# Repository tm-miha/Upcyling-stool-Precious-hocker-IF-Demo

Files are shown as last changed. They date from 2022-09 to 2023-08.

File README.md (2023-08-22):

<!--
SPDX-FileCopyrightText: regenholz <mail@regenholz.de>

SPDX-License-Identifier: CC-BY-NC-SA-4.0
-->

# Upcycling stool and side table furniture "Precious Hocker"

## General info and a bit of context

The "Precious Hocker" project was developed during the [Building workshops](https://www.interfacerproject.eu/news/buildworkshops/) of the [Interfacer Project](https://www.interfacerproject.eu/) by [regenholz](https://regenholz.de) and was cloned for demo purposes from the [gitlab.fabcity.hamburg](https://gitlab.fabcity.hamburg/hardware/interfacer-osh-build-workshops/upcycling-moebelbau-holz-preciousplastic ) account.

## Hardware Description

The "Precious Hocker" is an upcycling product used as a sitting stool or as a piece of furniture for storage in the living room (laptop, tablet, magazines, drinks, snacks, plants, etc.). The wood comes from discarded spruce planks from scaffolding construction, the plastic frame is cast from plastic waste (shredded plastic lids).

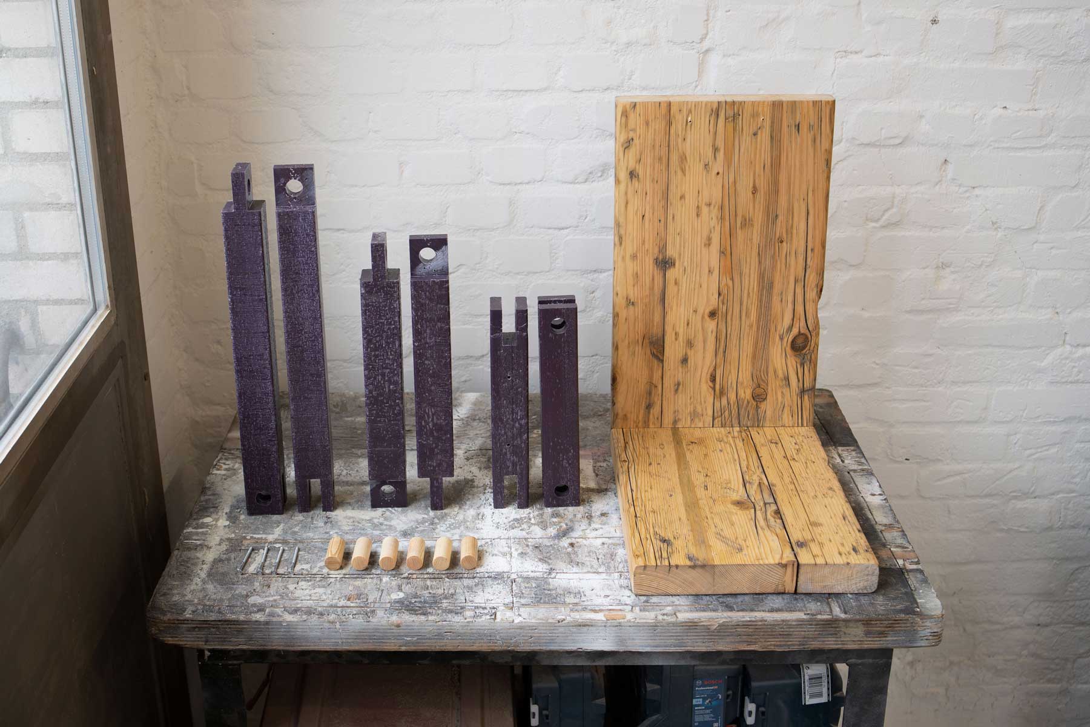
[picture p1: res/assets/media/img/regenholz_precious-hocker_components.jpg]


**Object:**

- Dimensions approx. 550x350x450 mm
- Weight approx. 5 kg

## Key Ressources

- [BOM file](bom.csv)
- [Dimensions](src/mech/dimension-drawing.md)
- [Workshop Description](doc/workshops/build/workshop-description+agenda_de.md)
- [Step-by-Step-Guide](doc/workshops/build/step-by-step_build-guideline.md)

## License

Hardware design, CAD and PCB files, BOM, settings and other technical or design files are released under the following license:
- CERN Open Hardware Licence Version 2 Weakly Reciprocal - **[CERN-OHL-W](/LICENSES/LICENSE_CERN_OHL_W_V2.txt)**

Assembly manual, pictures, videos, presentations, description text and other type of media are released under the following license:
- Creative-Commons-Attribution-NonCommercial-ShareAlike 4.0 International - **[CC-BY-NC-SA 4.0](/LICENSES/CC-BY-NC-SA-4.0.txt)**

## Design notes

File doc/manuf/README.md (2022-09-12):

# README `doc/manuf/`

Manufacturing instructions manual sources - Manufacturing means: Details about how to get from the sources under src/elec/ and src/mech/ to the actual parts, so this contains the meta-data about, and describes the process of 3D-printing, milling, carving, ... the individual parts. See also: doc/assembly/.

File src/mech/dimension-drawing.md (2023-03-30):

# Vermaßung

Die Dimensionen des Hockers lassen sich je nach Material und Stärke variieren.



## Vermaßung Objekt

- Tiefe: 450 mm
- Breite: 350 mm
- Höhe: 550 mm



## Zuschnitte Holzbohlen 

- Materialstärke: 45 mm
- Bohlenbreite: 350 mm
- 1x Platte 1, Länge: 450 mm Außenmaß auf 45°
- 1x Platte 2, Länge: 550 mm Außenmaß auf 45°

## Zuschnitte Plasktikbalken 

- Materialstärke: 52x52 mm
- 2x Balken 1, Länge: 350 mm
- 2x Balken 2, Länge: 405 mm
- 2x Balken 3, Länge: 505 mm

- 6x Löcher für Rundstäbe: Forstnerbohrer 22 mm Durchmesser

## Zuschnitte Rundstäbe

Durchmesser:22 mm
6x Rundstab, Länge: 52 mm

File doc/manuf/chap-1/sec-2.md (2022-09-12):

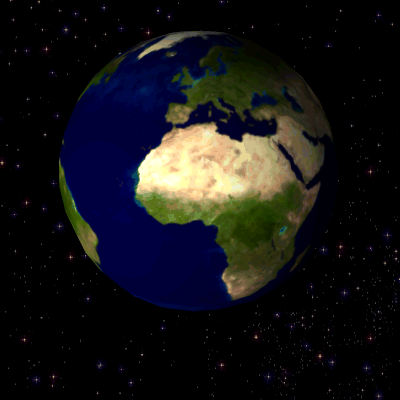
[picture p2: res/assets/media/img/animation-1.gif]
image X


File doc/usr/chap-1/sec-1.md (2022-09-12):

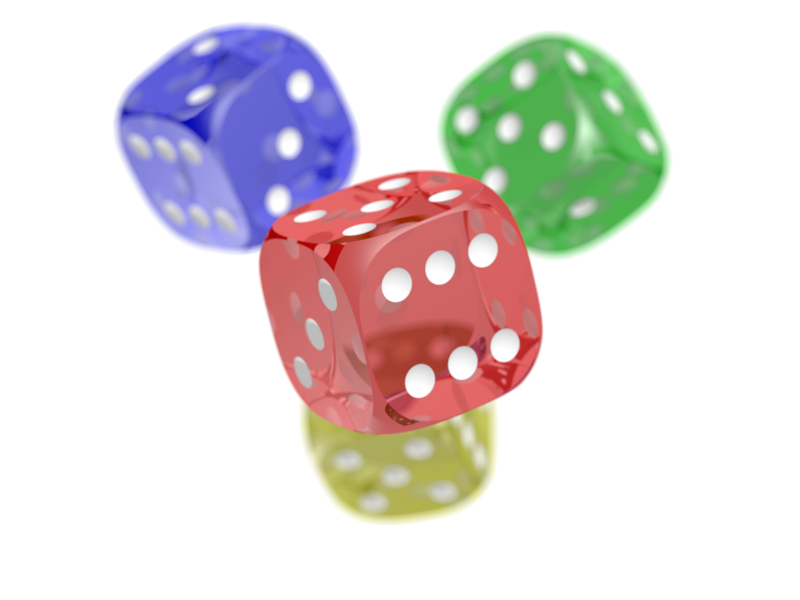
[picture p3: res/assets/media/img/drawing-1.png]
image X


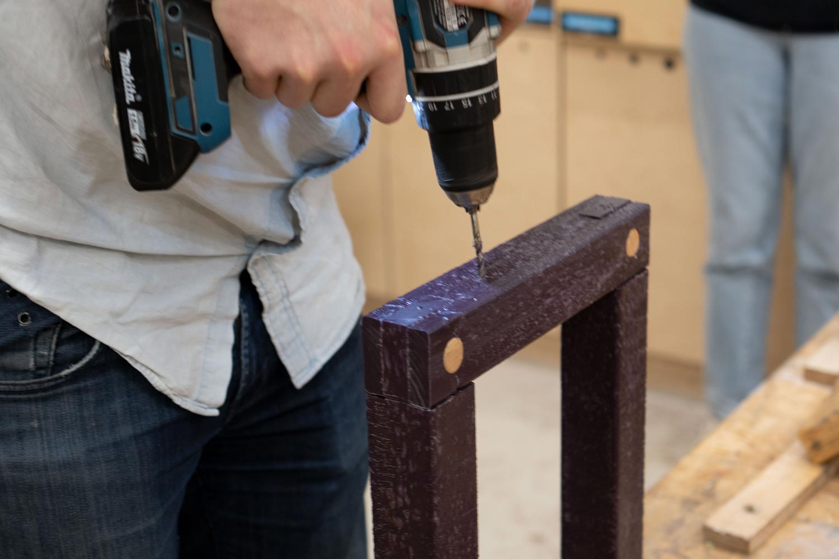
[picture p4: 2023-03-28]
res/assets/media/img/regenholz_precious-hocker_17-schraubloecher-vorbohren.jpg

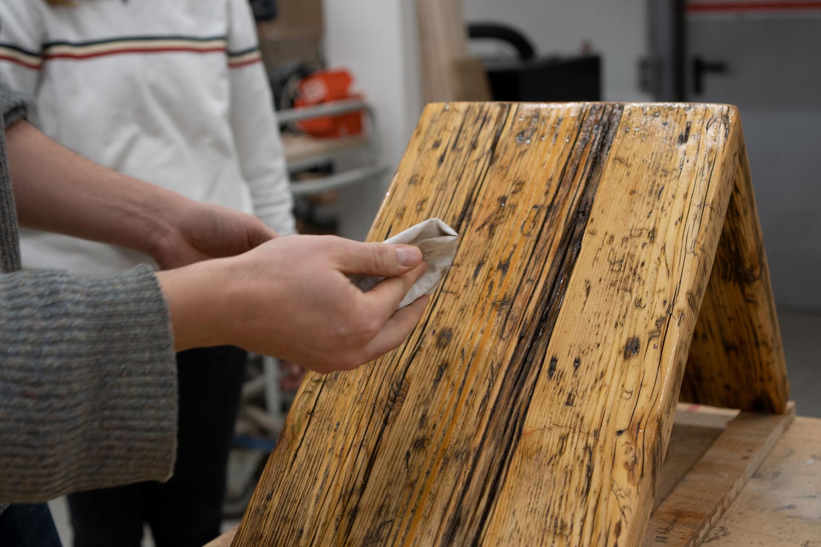
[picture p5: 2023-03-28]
res/assets/media/img/regenholz_precious-hocker_11-oelen.jpg

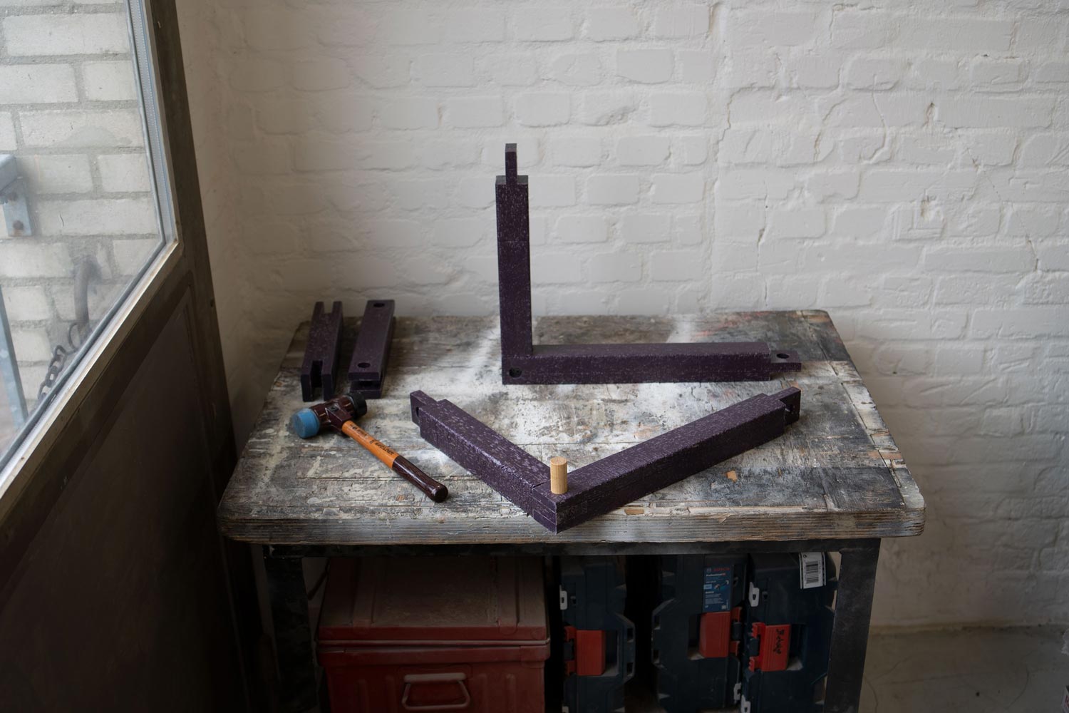
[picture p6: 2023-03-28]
res/assets/media/img/regenholz_precious-hocker_20-gestell-bauen.jpg

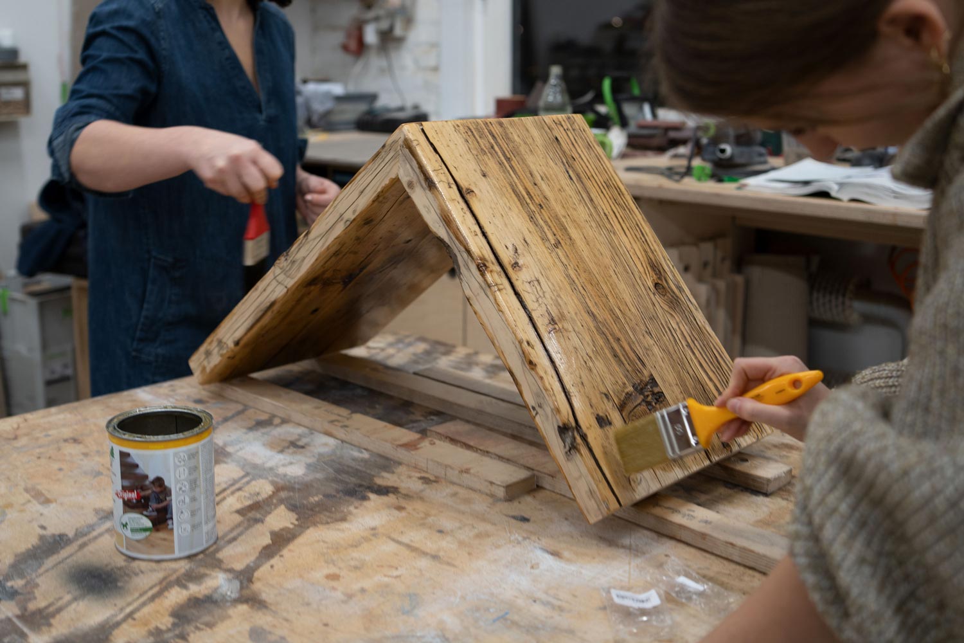
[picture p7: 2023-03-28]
res/assets/media/img/regenholz_precious-hocker_10-oelen.jpg

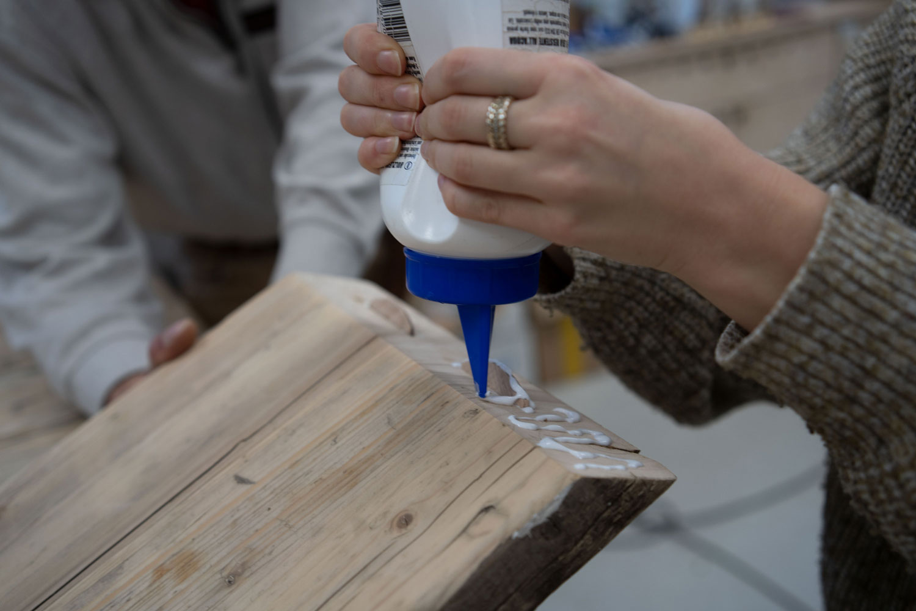
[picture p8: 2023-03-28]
res/assets/media/img/regenholz_precious-hocker_05-verleimen.jpg

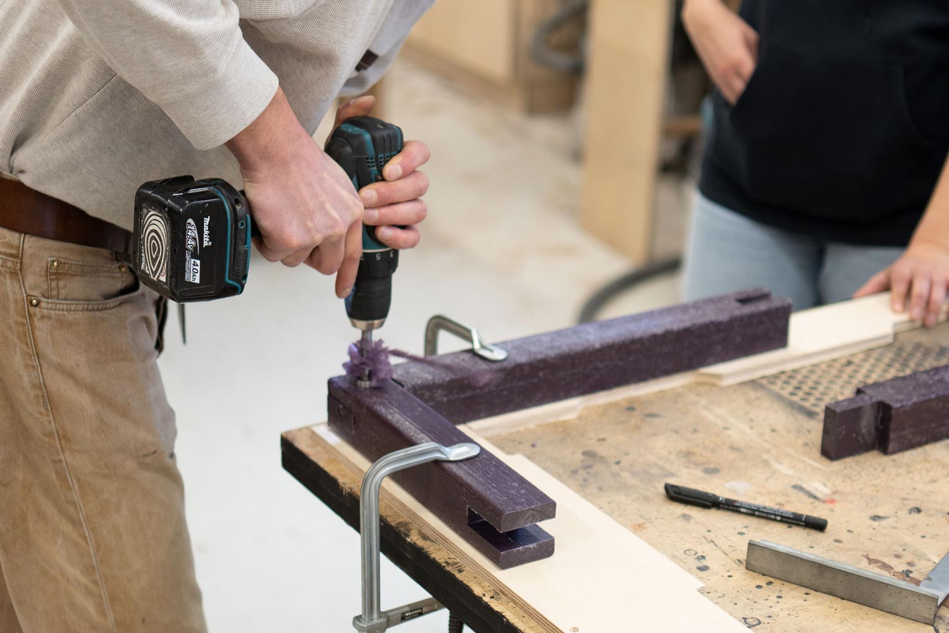
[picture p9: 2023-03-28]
res/assets/media/img/regenholz_precious-hocker_14-verbindungen-bohren.jpg

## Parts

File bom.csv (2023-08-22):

PartID | Module | Part-Name EN | Part-Name DE | Quantity | Description EN | Description DE | Supply-Type | Doc-Ref | Manufacturer | Manufacturer-PartNo. | Supplier | Supplier-PartNo. | Remarks
1 |  | Scaffolding board | Gerüstbohle | 1 | Spruce, untreated, 1000x320x45 mm | Fichte, unbehandelt, 1000x320x45 mm | OSH |  | any |  | Wholeseller
2 |  | Plastic bars | Plastic Balken | 1 | Precious Plastic, approx. 4.5 kg flakes, 2500x52x52 mm | Precious Plastic, ca. 4,5 kg Flakes, 2500x52x52 mm | OSH |  | Precious Plastic |  | Precious Plastic |  | https://community.preciousplastic.com/map
3 |  | Sandpaper | Schleifpapier | 3 | Sandpaper, 180 grit | Schleifpapier, 180er | OSH |  | any |  | Hardware Store |  | https://www.contorion.de/p/klingspor-scheibe-ps-22-k-mit-papierunterlage-kletthaftend-fuer-holz-metall-universal-lochform-gsl51-c93899168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
4 |  | Screws | Schrauben | 4 | Countersunk chipboard screws, 4x60 | Senkkopf-Spanplattenschrauben, 4x60 | OSH |  | any |  | Hardware Store |  | https://www.contorion.de/p/stier-senkkopf-spanplattenschraube-4x60-stahl-galvanisch-verzinkt-gelb-tx-20-76769363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
5 |  | Wood glue | Holzleim | 1 | wood glue | Holzleim | OSH |  | any |  | Hardware Store |  | https://www.contorion.de/p/ponal-holzleim-wasserfest-super-3-c73102079?q=holzleim
6 |  | Hard wax oil | Hartwachs-Öl | 1 | Hard wax oil, 0.25 l | Hartwachs-Öl, 0,25 l | OSH |  | any |  | Hardware Store |  | https://www.osmoshop.com/innen/fussboden-hartwachs-oel/28/osmo-hartwachs-oel-original?number=3032-750
7 |  | Wooden slats | Holzlamellen | 2 | Wooden slats, 10x53 mm | Holzlamellen, 10x53 mm | OSH |  | any |  | Hardware Store |  | https://www.contorion.de/p/lamello-holzlamellen-original-c83909010?$ps=1000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
8 |  | Round wooden stick | Rundholzstab | 1 | Round wooden stick, diameter, 22 mm | Rundholzstab, Durchmesser, 22 mm | OSH |  | any |  | Hardware Store

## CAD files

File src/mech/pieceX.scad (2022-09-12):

// SPDX-FileCopyrightText: 2021 Jens Meisner <jens.meisner@ose-germany.de>
//
// SPDX-License-Identifier: CC-BY-SA-4.0

/*File Info--------------------------------------------------------------------
File Name: PoleBase.scad
Project Name: OpenHardware LOOM - OHLOOM
License: Attribution-ShareAlike 4.0 International (CC BY-SA 4.0) 
Name: Jens Meisner
Date: 08/01/20
Desc:  This file is part of the OHLOOM Project. Original design by Oliver Slueter, who made all wooden parts without a CNC Router. https://wiki.opensourceecology.de/Open_Hardware-Webstuhl_%E2%80%93_OHLOOM
Usage: 
./OHLoom_Documentation/Assembly_Guide/AssemblyGuide.md
./OHLoom_Documentation/User_Guide/OHLOOM_UserGuide.md
/*
/*Modifications------------------------------------------------------------
New File Name: Enter name, if it has changed
Name: Enter name of author
Date: 
Desc: Describe changes of the original design
*/
//Please continue with any fur enter any further modification here
//--------------------------------------------------------------------------------

d1=47;  //outer diameter
d2=37;  //inner diameter
h1=100; //cylinder height
h2=5;   //base thickness

union()
{
    hull()
    {
        translate([-d2/4,-d2*1.8,0])
        cylinder(h=h2,d=d2);
        translate([d2/4,-d2*1.8,0])
        cylinder(h=h2,d=d2);
        translate([-d2,d2/1.5,0])
        cylinder(h=h2,d=d2);
        translate([d2,d2/1.5,0])
        cylinder(h=h2,d=d2);
    }
    difference()
    {
        union()
        {
            cylinder(h=h1,d=d1);
            translate([0,h2/2,d1/2])
            rotate([90,30,0])
            cylinder(h=h2,d=d1*1.8,$fn=3);
            translate([h2/2,0,d1/2])
            rotate([90,30,-90])
            cylinder(h=h2,d=d1*1.8,$fn=3);
        }       
        cylinder(h=h1,d=d2);
    }
}

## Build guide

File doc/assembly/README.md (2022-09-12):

# README `doc/assembly/`

Assembly instructions manual sources - Assembly means: You have all the parts available (bought, printed, milled, ...), and now want to put them together. So this is like a LEGO or IKEA manual. See also: doc/manuf/.

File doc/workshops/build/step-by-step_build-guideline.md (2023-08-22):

<!--
SPDX-FileCopyrightText: regenholz <mail@regenholz.de>

SPDX-License-Identifier: CC-BY-NC-SA-4.0
-->

# Build Process - Step by Step Guide



## Work steps overview:

### 1. Wood processing
- [Planks cut / mitred](#planks-cut-mitred)
- [Lamello](#lamello)
- [Grinding inside](#innenseite-schleifen)
- [Glueing](#verleimen)
- [Plastering break edges](#verputzen-kanten-brechen)
- [Grinding the outside](#außenseite-schleifen)
- [Oiling](#ölen)

### 2. Plastic processing

- [Beam cutting](#balken-zuschnitt)
- [Connections saws](#verbindung-sägen)
- [Drill connections](#verbindungen-bohren)
- [Pre-drill screw holes](#schraubenlöcher-vorbohren)
- [Sawing round bars](#rundstäbe-sägen)
- [Build rack](#gestell-bauen)

### 3. Assembly
- [Montage](#montage)

<br/>

## 1. Wood processing:

### Planks cut / mitred
The metal ends are cut off the scaffolding planks. The planks are then cut to size and provided with a 45° miter on the abutting edge.

 

### Lamello
The planks are aligned and marked. Grooves for the lamellas are milled on the miter cut with the lamella milling cutter. When gluing, these are used to ensure that the two planks remain in position and do not slip when they are clamped.

 

### Grinding inside
Before the planks are glued, we close the inside, as it is more difficult to grind at an angle afterwards.

 

### Glueing
The glue is applied to the miter cut with the Lamellos. Adhesive tape is then quickly positioned and pulled tight so that the planks stick together as best as possible. Excess glue is wiped away with a damp cloth.





### Plastering break edges 
After the glue has dried and the clamps have been loosened, the edges of the plank are broken off and any excess is repaired. This means that the edges are sanded flush all around.



### Grinding the outside
Then all other wooden surfaces are sanded evenly with 180 grit sandpaper.



### Oiling
After sanding, the wood is treated on all sides with hard wax oil, a brush and a cloth and left to dry for at least 12 hours with good ventilation.




## 2. Plastic processing

### Beam cutting
The plastic beams are cut to size.



### Connections saws
Connections are marked on the bars. Saw is adjusted to beam height. Width stop to ⅓ of the beam thickness. (Note the tear side!) Slot and tenon connections are sawn.



### Drill connections
Holes for the round wooden rods are drilled in the center of the connections with a Forstner bit.




### Pre-drill screw holes
The holes for the screws are pre-drilled on the beams that will later be drilled onto the wood.




### Sawing round bars
The round bars are sawn to the beam thickness.




### Build rack
The beams are plugged into each other and the round rods are inserted into the connections.




## 3. Montage
The finished frame is aligned with the glued wood and connected with the screws. 






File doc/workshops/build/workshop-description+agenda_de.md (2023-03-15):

<!--
SPDX-FileCopyrightText: regenholz <mail@regenholz.de>

SPDX-License-Identifier: CC-BY-SA-4.0
-->
# Workshop Inhalte

## Build Workshop Upcycling Möbel

### Ziel

Bei dem Workshop entsteht ein Würfel-Möbel, das z.B. als Hocker, Beistelltisch oder Blumenständer genutzt werden kann. Beim Bau werden gebrauchte Materialien verwendet: Das Eichenholz stammt von ausrangierten Holzbohlen aus dem Gerüstbau, das Plastikgestänge wird aus Plastikmüll (geschredderten Plastikdeckeln) gegossen. Der Workshop vermittelt den Umgang mit: Tischkreissäge, Akkuschrauber, Exzenterschleifer, Oberfräse mit Viertelstabfräser und einem sogenannten "Extruder" für die Herstellung der Plastikteile.

### Vorbereitung

**Vorfertigung der Precious Plastic Balken**

Zur Herstellung des upcycling Möbelstücks werden für die Herstellung des Rahmengerüsts Balken aus recyceltem Plastik benötigt. Diese werden durch einen Extruder aus feinem Granulat gefertigt, indem es stark erhitzt, unter Druck gesetzt und in ein Stahl Vierkant-Rohr gepresst wird. Dieser Prozess dauert inkl. Kühlzeit ca. 2 Stunden wobei damit der Rahmen für einen Hocker/ Beistelltisch hergestellt wird.

**Aussortierte Gerüstbohlen organisieren und trocken lagern**

Weiterhin ist Holz der weitere Baustoff, der hier recycelt und verwendet wird. Dafür werden Gerüstbohlen verwendet, welche aufgrund von Arbeitssicherheit aussortiert wurden und nun handverlesen zu uns transportiert und trocken gelagert werden müssen. 

### Folgende Themengebiete werden behandelt:

**Fertigkeiten vermitteln: Traditionelles und digitales Handwerk**

- Schleifen (Exzenterschleifer, Oberfräse mit Viertelstabfräser)
- Ölen (Hartwachsöl)
- Sägen (Tischkreissäge)
- Verleimen (Holzleim, Klebeband, Zwingen)
- Bohren und Schrauben (Akkuschrauber)

**Wissen vermitteln: Nachhaltige Materialien und Fertigungstechniken**

Ein Hauptaugenmerk wird auf der Wissensvermittlung zu den verwendeten Materialien und dem nachhaltigen Produzieren liegen. Der Workshop vermittelt u.a. praktische Einblicke in die technischen Herausforderungen und Möglichkeiten für das Recycling von Plastik und Holz auf dem Weg zur Kreislaufwirtschaft auf globaler und lokaler Ebene.

### Zielgruppe

**Vorkenntnisse**

Die Workshops richten sich an Leute jeden Alters, die grundlegendes technisches Verständnis haben. Es werden keine handwerklichen Vorkenntnisse benötigt. Die von den Teilnehmer:innen ausgeführten Arbeitsschritte sind traditionelle Handwerksarbeiten (Schleifen, Ölen, Sägen, Fräsen) und werden von den Workshopleiter:innen beigebracht und gemeinsam durchgeführt.

**Barrieren**

Belastbarkeit: Die Arbeiten werden zum großen Teil stehend ausgeführt

### Organisation

Es gibt 2 Workshopleitende für bis zu 8 Teilnehmende pro Workshop. Je zwei Teilnehmende bauen zusammen einen Hocker. Insgesamt entstehen in einem Workshop mindestens 3 Werkstücke. Der Aufbau wird eher Schritt für Schritt gemeinsam durchgeführt. Eventuell wird es parallele Stationen geben.

### Infrastrukturanforderung an Produktionsort

**Werkzeuge und Maschinen**
- Tischkreissäge
- Akkuschrauber
- Handoberfräse
- Exzenterschleifer
- Laptop

**Materialien**
- Fichtenholz (Gerüstbohlen)
- Precious Plastic (4,5 kg Flakes pro Hocker)
- Schrauben
- Fräsköpfe
- Bits
- Forstnerbohrer (? mm Durchmesser)
- Schleifpapier
- Öl
- Lappen
- Handschuhe
- Schutzbrille
- Ohrschutzhörer

**Raum**
- Arbeisttische
- Stühle
- Laptop für Präsentation

# Workshop Agenda

|Abschnitt | Zeit | Punkt | Personen | Notiz |
|-----| --- | --- | ---- | --- |
|`TAG 1` | 10:00 | **Ankommen** |  gemeinsam | Ort kennenlernen|
| Einführung | 10:30  | **Vorstellung - Fab City Hamburg und Open Source Hardware** | Workshopleitende | - Vorstellungsrunde <br>- Was ist Fab City<br>- Was ist ein Fab Lab<br>- Was ist Open Source Hardware? |
| Einführung | 10:45 | **Vorstellung - Upcyling Möbel Projekt** | Workshopleitende | Einblicke in die konkreten technischen Herausforderungen und Möglichkeiten für das Recycling von Plastik und Holz auf dem Weg zur Kreislaufwirtschaft auf globaler und lokaler Ebene  |
| Workshop Vorbereitung | 11:00 | **Workshop Material und Ablauf** | gemeinsam | - Sicherheitshinweis<br>- Materialien kennenlernen<br>- Arbeitsschritte kennenlernen |
| Workshop - Fertigung | 11:15 | **Sägen: Zuschnitt und Gehrung** | Gruppen | Die Metallenden werden von den Gerüstbohlen abgeschnitten. Danach werden die Bohlen auf Maß geschnitten und an der Stoßkante mit einer 45° Gehrung versehen. |
| Workshop - Fertigung | 12:15 | **Verbindung vorbereiten: Fräsen und Schleifen** | Gruppen | Die Bohlen werden ausgerichtet und angezeichnet. Mit dem Lamellofräser werden am Gehrungsschnitt Nuten für die Lamellos gefräst. Diese dienen beim Verleimen dazu, dass die zwei Bohlen in Position bleiben und beim festzwingen nicht verrutschen. Bevor die Bohlen verleimt werden, schleifen wir die Innenseite, da es im Nachhinein schwieriger ist im Winkel zu schleifen.  |
| `PAUSE` | 13:00 | **Mittagessen** | gemeinsam |  |
| Workshop - Fertigung | 14:00 | **Verleimen** | Gruppen | Der Leim wird an den Gehrungsschnitt mit den Lamellos aufgetragen. Zügig wird dann Klebeband positioniert und fest gezogen, damit die Bohlen bestmöglich aneinander haften. Überflüssiger Leim wird mit einem feuchten Tuch weggewischt. |
| Workshop - Fertigung | 15:00 | **Verputzen / Kanten brechen** | Gruppen | Nachdem der Leim getrocknet ist und die Zwingen gelöst wurden, werden die Kanten der Bohle gebrochen und Überstände ausgebessert. Das bedeutet, dass die Kanten rundherum bündig geschliffen werden. |
| Workshop - Fertigung | 15:30 | **Schleifen und Ölen** | Gruppen | Darauf werden alle weiteren Holzflächen mit 180er Schleifpapier gleichmäßig geschliffen. Nach dem Schleifen wird das Holz von allen Seiten mit Hartwachs Öl, Pinsel und einem Tuch behandelt und zum Trocknen mindestens 12 Stunden gut belüftet liegen gelassen.
| Workshop - Nachbereitung | 16:00 | **Arbeitsplätze aufräumen und Feedbak / Austausch** | gemeinsam |  |

---

|Abschnitt | Zeit | Punkt | Personen | Notiz |
|-----| --- | --- | ---- | --- |
| `TAG 2` | 10:00  | **Ankommen + Review Tag 1** | gemeinsam | - offene Fragen beantworten <br>- Vorbereiten Tag 2|
| Workshop - Fertigung | 10:30  | **Rundstab- und Schraubenlöcher bohren** | Gruppen | Mit einem Forstnerbohrer werden mittig in den Verbindungen Löcher für die Holzrundstäbe gebohrt. An den Balken, die später an das Holz gebohrt werden, werden die Löcher für die Schrauben vorgebohrt. |
| Workshop - Fertigung | 11:15  | **Rundstäbe sägen** | Gruppen | Die Rundstäbe werden auf die Balkenstärke zugesägt.|
| Workshop - Montage | 12:00  | **Teile verbinden** | Gruppen | Die Balken werden über die Schlitz- und Zapfenverbindungen ineinander gesteckt. In die vorgebohrten Löcher werden die Rundstäbe eingesetzt. Das fertige Gestell wird mit dem verleimten Holz ausgerichtet und über die Schrauben verbunden. |
| `PAUSE` | 13:00 | **Mittagessen** | gemeinsam |  |
| Workshop - Testing | 14:00  | **Hocker testen** | gemeinsam | Belasten, drehen, wenden etc. |
| Workshop - Wissensvermittlung | 14:30  | **Präsentation und Diskussion** | gemeinsam | - Kreislauffähige Möbelproduktion<br>- Holz Recycling<br>- Holz Zertifizierung<br>- Kunststoffarten und Nutzungsdauer<br>- Precious Plastic Universum |
| Workshop Nachbereitung | 15:00  | **Arbeitsplätze aufräumen und Feedback / Austausch** | gemeinsam | Austausch, Gedanken und Impressionen |

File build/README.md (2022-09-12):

# README `build/`

Where everything generated should en up; this is not tracked in git/SCM

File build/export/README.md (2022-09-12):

# README `build/export/`

TODO What is this meant to be? -> Ask pieter and if no idea, delete!

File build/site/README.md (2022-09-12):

# README `build/site/`

Generated website of the project (for example, for hosting on github or gitlab pages)

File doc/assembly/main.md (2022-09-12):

[C1 S1](chap-1/sec-1.md) [C1 S2](chap-1/sec-2.md)

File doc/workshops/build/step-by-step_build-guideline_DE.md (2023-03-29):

<!--
SPDX-FileCopyrightText: regenholz <mail@regenholz.de>

SPDX-License-Identifier: CC-BY-NC-SA-4.0
-->

# Build Process - Step by Step Guide

 

## Arbeitsschritte Übersicht:

### 1. Holzverarbeitung
- [Bohlen Zuschnitt / Gehrung](#bohlen-zuschnitt-gehrung)
- [Lamello](#lamello)
- [Innenseite schleifen](#innenseite-schleifen)
- [Verleimen](#verleimen)
- [Verputzen/ Kanten brechen](#verputzen-kanten-brechen)
- [Außenseite schleifen](#außenseite-schleifen)
- [Ölen](#ölen)

### 2. Plastikverarbeitung
- [Balken Zuschnitt](#balken-zuschnitt)
- [Verbindungen Sägen](#verbindung-sägen)
- [Verbindungen Bohren](#verbindungen-bohren)
- [Schraubenlöcher vorbohren](#schraubenlöcher-vorbohren)
- [Rundstäbe sägen](#rundstäbe-sägen)
- [Gestell bauen](#gestell-bauen)

### 3. Zusammenbau
- [Montage](#montage)

<br/>

## Arbeitssschritte:

### Bohlen Zuschnitt / Gehrung
Die Metallenden werden von den Gerüstbohlen abgeschnitten. Danach werden die Bohlen auf Maß geschnitten und an der Stoßkante mit einer 45° Gehrung versehen.

 

### Lamello
Die Bohlen werden ausgerichtet und angezeichnet. Mit dem Lamellofräser werden am Gehrungsschnitt Nuten für die Lamellos gefräst. Diese dienen beim Verleimen dazu, dass die zwei Bohlen in Position bleiben und beim festzwingen nicht verrutschen.

 

### Innenseite schleifen
Bevor die Bohlen verleimt werden, schleifen wir die Innenseite, da es im Nachhinein schwieriger ist im Winkel zu schleifen.

 

### Verleimen
Der Leim wird an den Gehrungsschnitt mit den Lamellos aufgetragen. Zügig wird dann Klebeband positioniert und fest gezogen, damit die Bohlen bestmöglich aneinander haften. Überflüssiger Leim wird mit einem feuchten Tuch weggewischt.





### Verputzen/ Kanten brechen 
Nachdem der Leim getrocknet ist und die Zwingen gelöst wurden, werden die Kanten der Bohle gebrochen und Überstände ausgebessert. Das bedeutet, dass die Kanten rundherum bündig geschliffen werden.



### Außenseite schleifen
Darauf werden alle weiteren Holzflächen mit 180er Schleifpapier gleichmäßig geschliffen.



### Ölen
Nach dem Schleifen wird das Holz von allen Seiten mit Hartwachs Öl, Pinsel und einem Tuch behandelt und zum Trocknen mindestens 12 Stunden gut belüftet liegen gelassen.




### Balken Zuschnitt
Die Plastikbalken werden auf Maß geschnitten.



### Verbindungen Sägen
Verbindungen werden auf die Balken angezeichnet. Säge wird auf Balkenhöhe eingestellt. Breitenanschlag auf ⅓ der Balkenstärke. (Rissseite beachten!) Schlitz und Zapfen Verbindungen werden gesägt.



### Verbindungen Bohren
Mit einem Forstnerbohrer werden mittig in den Verbindungen Löcher für die Holzrundstäbe gebohrt.




### Schraubenlöcher vorbohren
An den Balken, die später an das Holz gebohrt werden, werden die Löcher für die Schrauben vorgebohrt.




### Rundstäbe sägen
Die Rundstäbe werden auf die Balkenstärke zugesägt.




### Gestell bauen
Die Balken werden ineinander gesteckt und in die Verbindungen werden die Rundstäbe eingesetzt.




### Montage
Das fertige Gestell wird mit dem verleimten Holz ausgerichtet und über die Schrauben verbunden. 






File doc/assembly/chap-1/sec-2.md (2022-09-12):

image Y

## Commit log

2022-09-12 adding the template
    [bom.csv, pieceX.scad]
2023-03-15 Deleted bom.csv
    [bom.csv]
2023-03-15 Update bom.csv, doc/workshops/README.md Deleted doc/workshops/README.md
    [bom.csv]
2023-03-15 Replace bom.csv
    [bom.csv]
2023-08-22 Updated: Readme - intro section: Bom and Step By Step Guide EN
    [bom.csv]
